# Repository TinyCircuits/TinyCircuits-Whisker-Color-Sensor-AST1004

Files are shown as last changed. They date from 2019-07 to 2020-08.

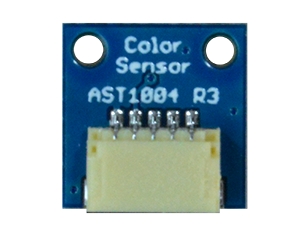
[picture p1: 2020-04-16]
images/AST1004-Learn-Photo-02.png

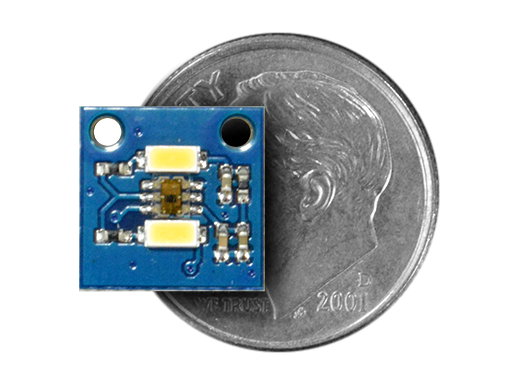
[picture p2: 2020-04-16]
images/AST1004-Product-Photo-03.png

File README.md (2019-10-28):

# TinyCircuits Wireling Color Sensor
# AST1004 Rev 2

The design files are located under design_files/ for the TinyCircuits AST1004 Rev 2 PCB. This is a Wireling board which measures the color and temperature of ambient or reflected light and also features a low power mode. Output resolution is 16-bit per each channel (Red, Green, and Blue). Includes bright white LEDs to aid sensing applications that can be toggled on or off.

Format is in Cadsoft Eagle format - Eagle version 6.2 was used for the original design.

For more infomation on this, check out the product page at TinyCircuits.com

# License:

Design by TinyCircuits.
All design files are released under the Creative Commons Attribution Share-Alike 3.0 License, see the following link for details: http://creativecommons.org/licenses/by-sa/3.0

All text above must be included in any redistribution or derived design

This project uses designs and concepts developed as part of the Arduino project and the LilyPad project.  The TinyCircuits design files themselves (schematics, PCB and libraries) are not directly derived from these works' design files and have been created new, however the concepts and basic architecture behind the TinyDuino and TinyLily products are derived and we thank the hard work of the organizations below for their contributions to open-source hardware:
  
Original Arduino Uno Design by Team Arduino

LilyPad Arduino Design by Leah Buechley and Sparkfun Electronics

Please support the open-source hardware community

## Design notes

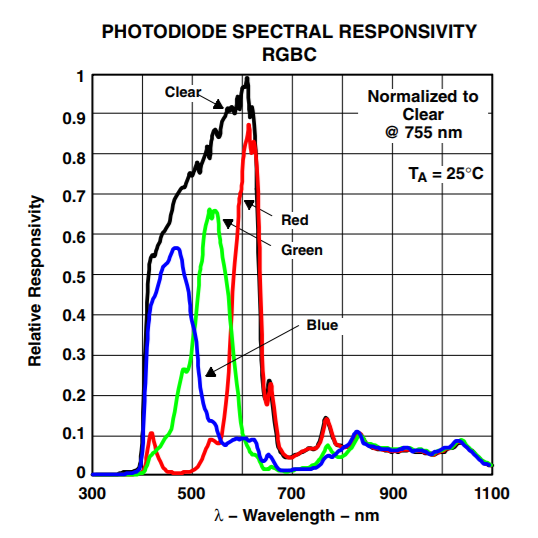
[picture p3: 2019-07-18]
images/Photodiode_Spectral_Responsivity.png

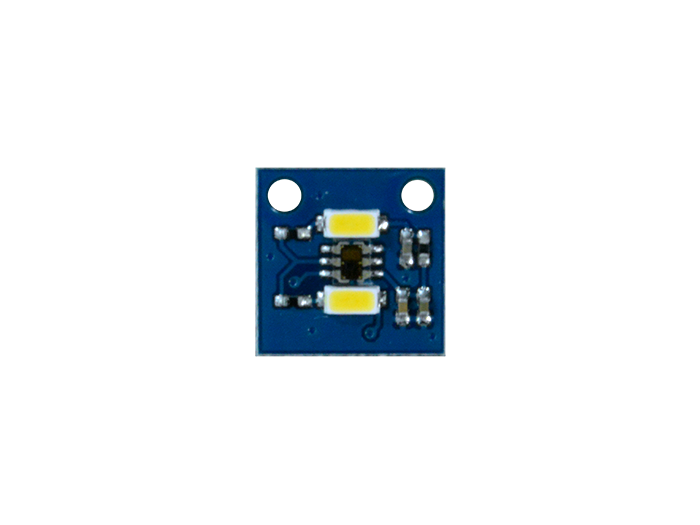
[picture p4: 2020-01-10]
images/AST1004-Product-Photo-01.png

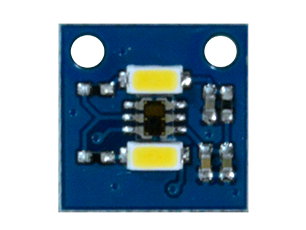
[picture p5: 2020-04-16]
images/AST1004-Learn-Photo-01.png

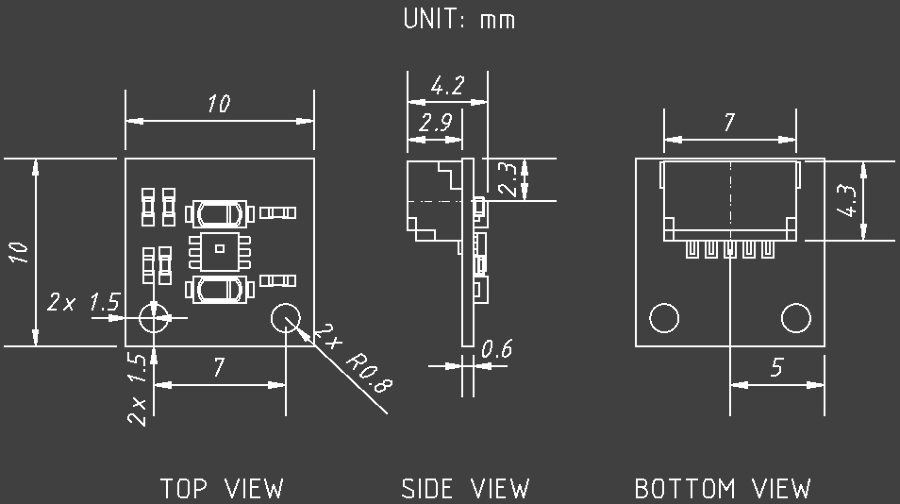
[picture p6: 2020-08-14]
cad/Wireling_COLORSENSOR_AST1004_REV3-DETAILED_DRAWING_COMPACT-PNG.png

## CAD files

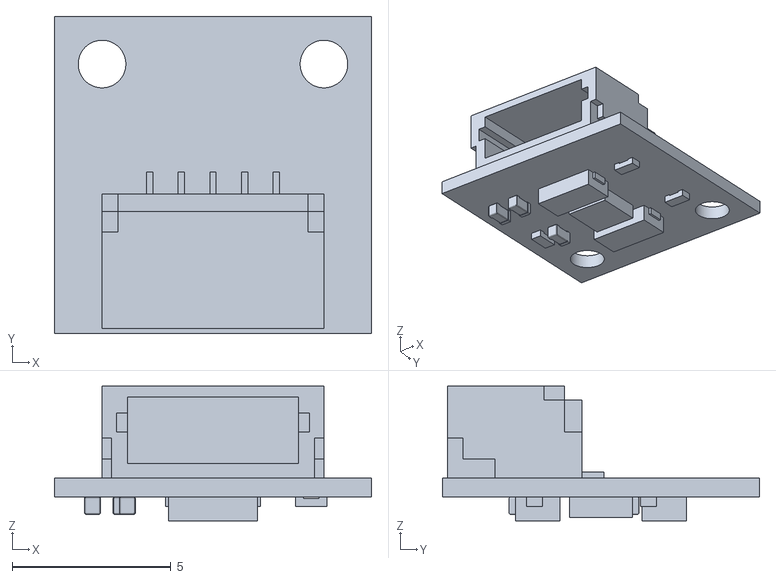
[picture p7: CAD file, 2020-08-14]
cad/Wireling_COLORSENSOR_AST1004_REV3-STL.stl
10.0 x 10.0 x 4.24

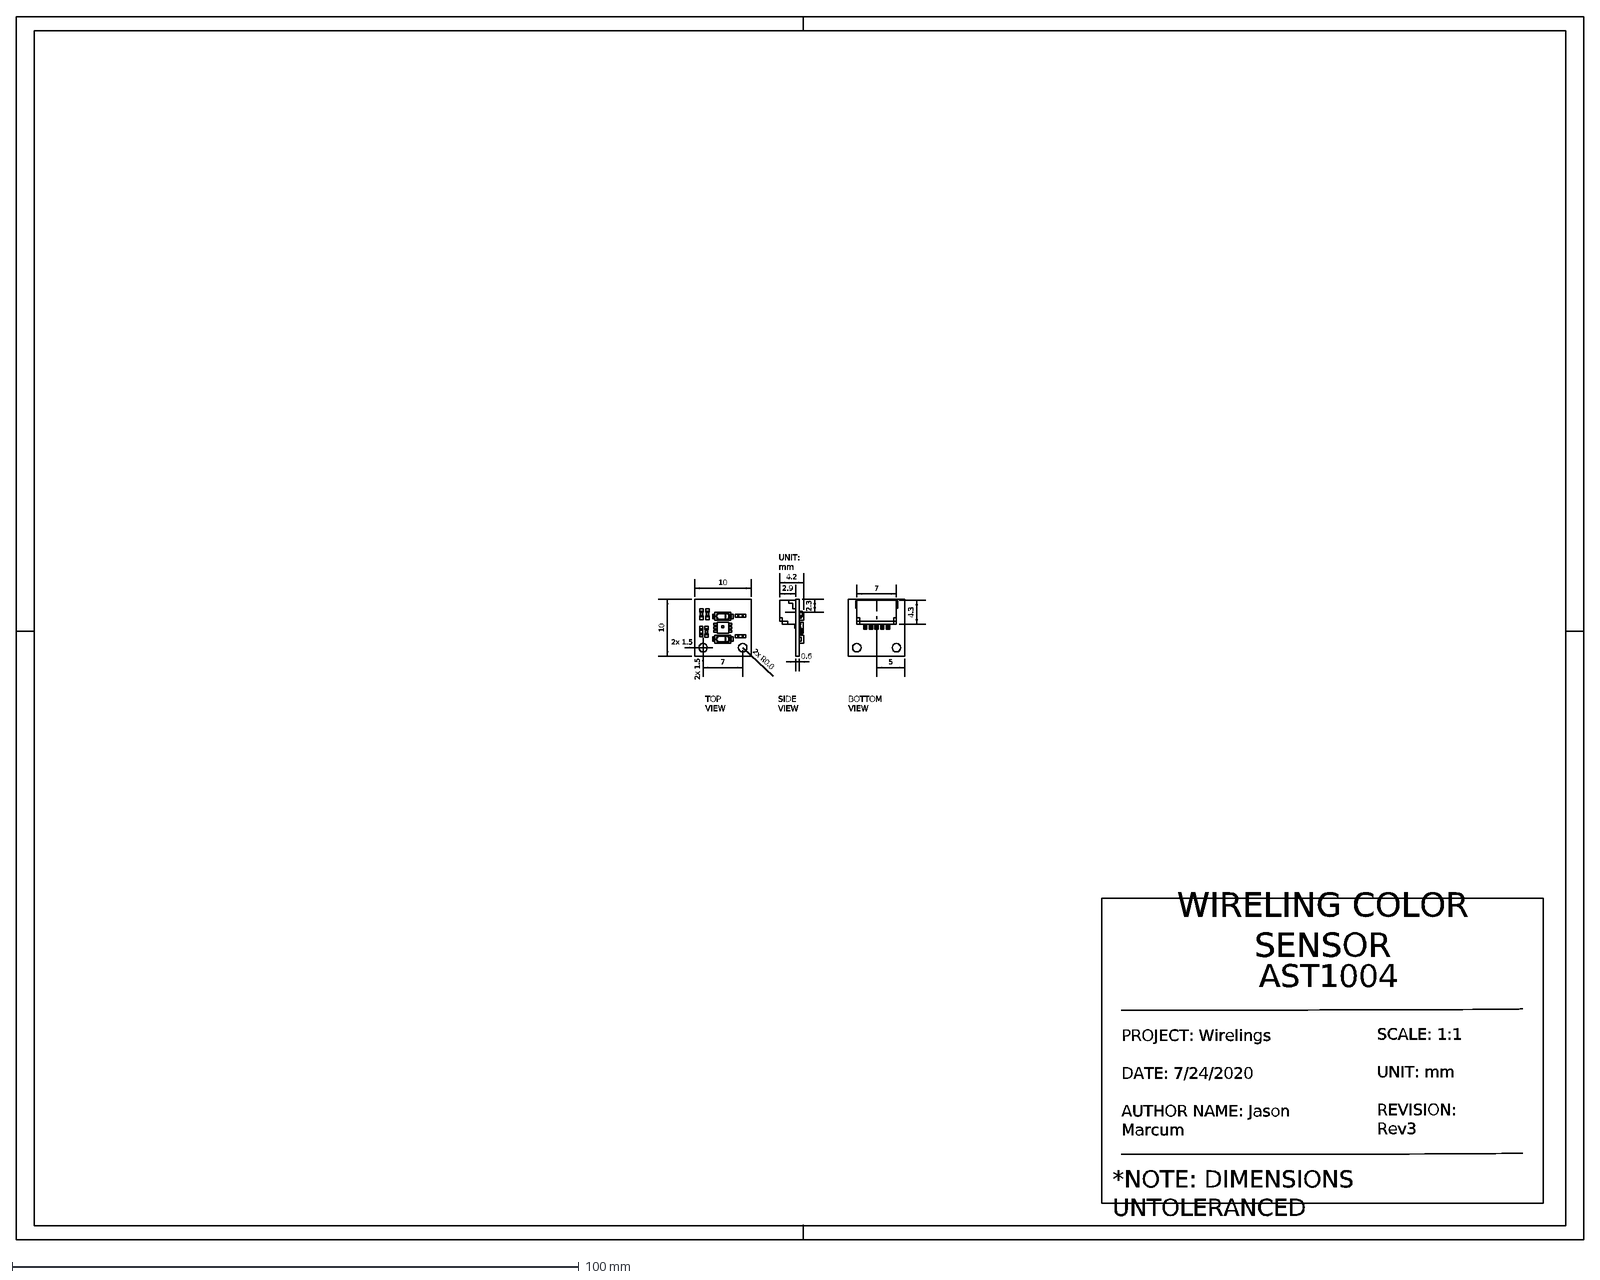
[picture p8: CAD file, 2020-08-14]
cad/Wireling_COLORSENSOR_AST1004_REV3-DETAILED_DRAWING-DXF.dxf
*NOTE: DIMENSIONS UNTOLERANCED
2x 1.5
7
10
2x R0.8
2.9
4.2
2.3
0.6
4.3
5
TOP VIEW
BOTTOM VIEW
SIDE VIEW
WIRELING COLOR SENSOR
AST1004
SCALE: 1:1 UNIT: mm REVISION: Rev3
UNIT: mm
PROJECT: Wirelings DATE: 7/24/2020 AUTHOR NAME: Jason Marcum

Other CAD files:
cad/Wireling_COLORSENSOR_AST1004_REV3-IGES.iges

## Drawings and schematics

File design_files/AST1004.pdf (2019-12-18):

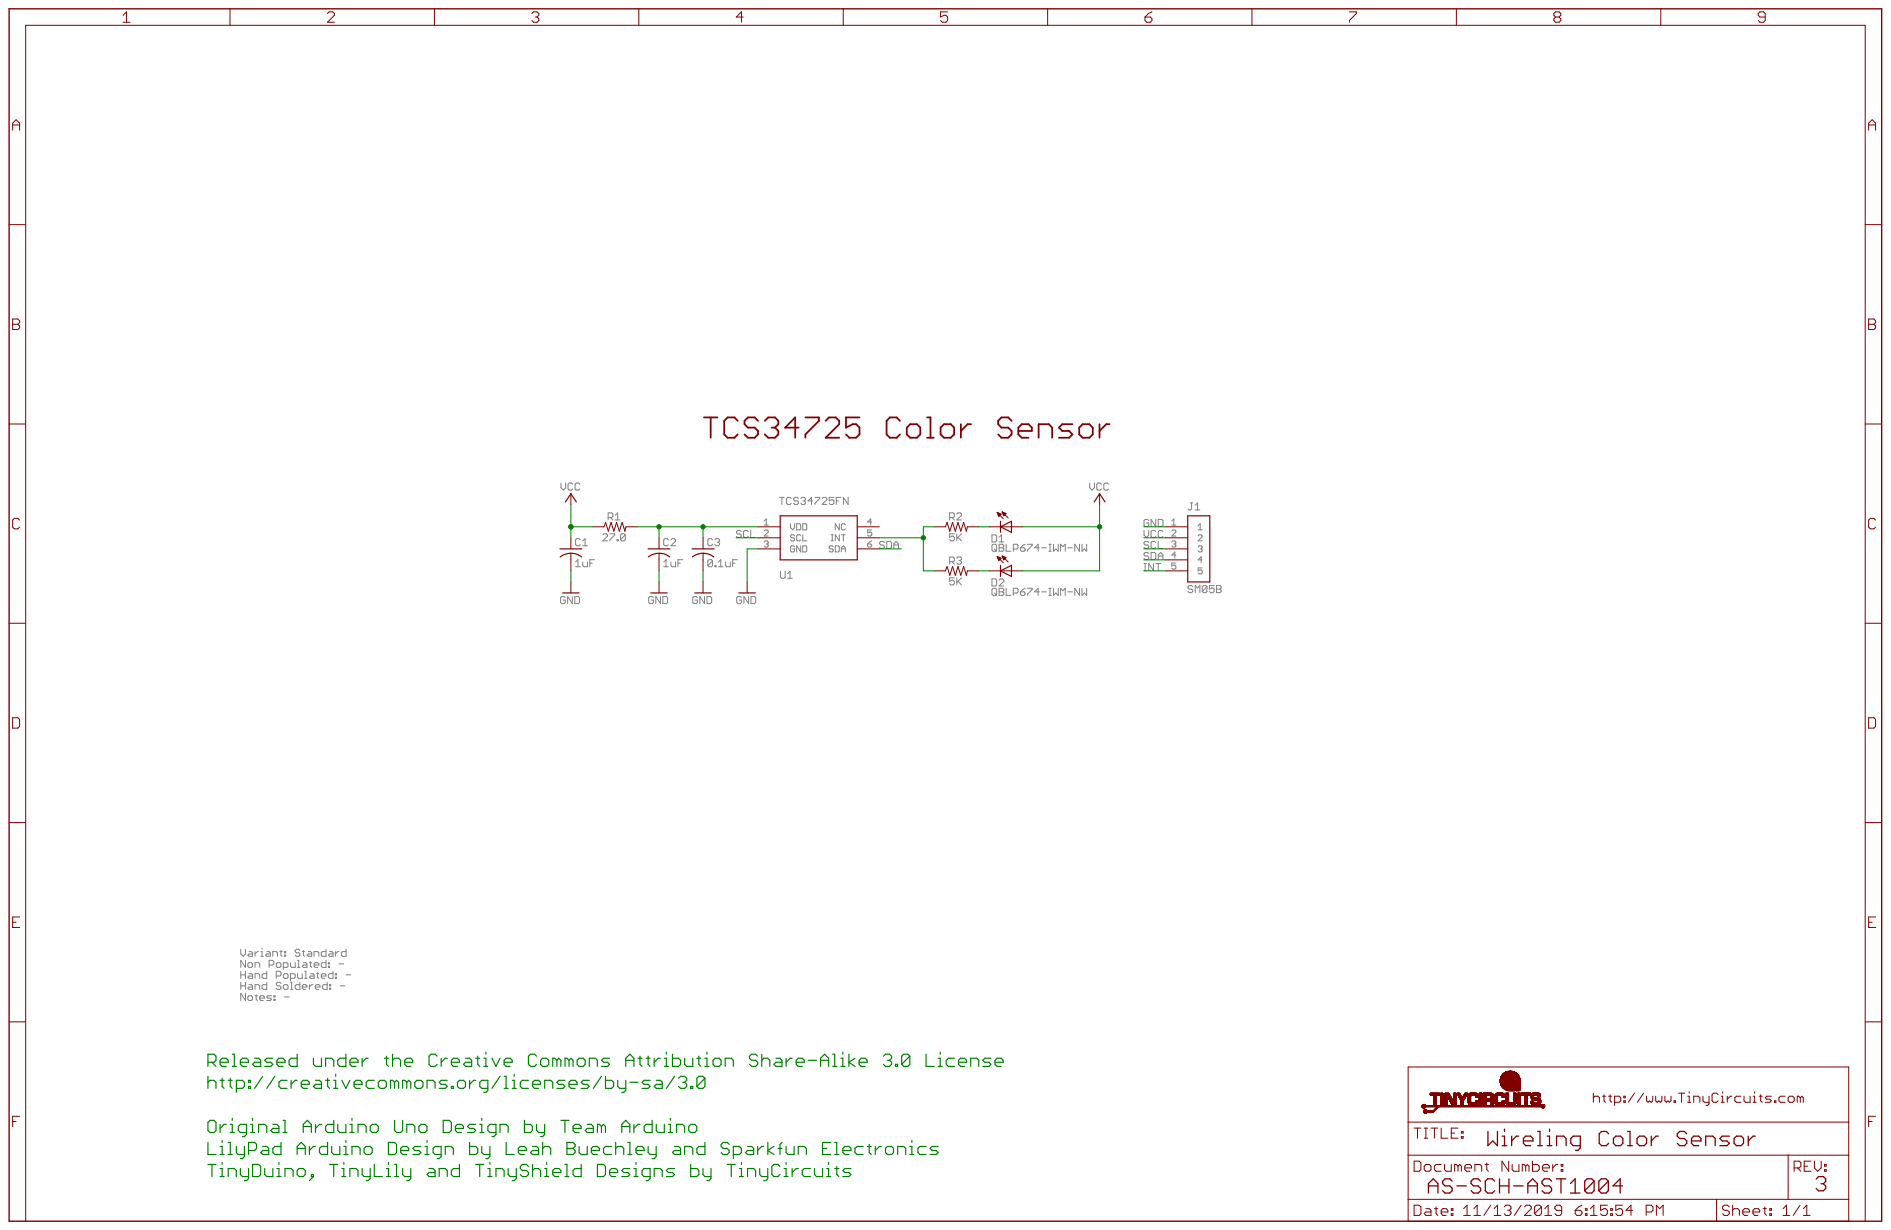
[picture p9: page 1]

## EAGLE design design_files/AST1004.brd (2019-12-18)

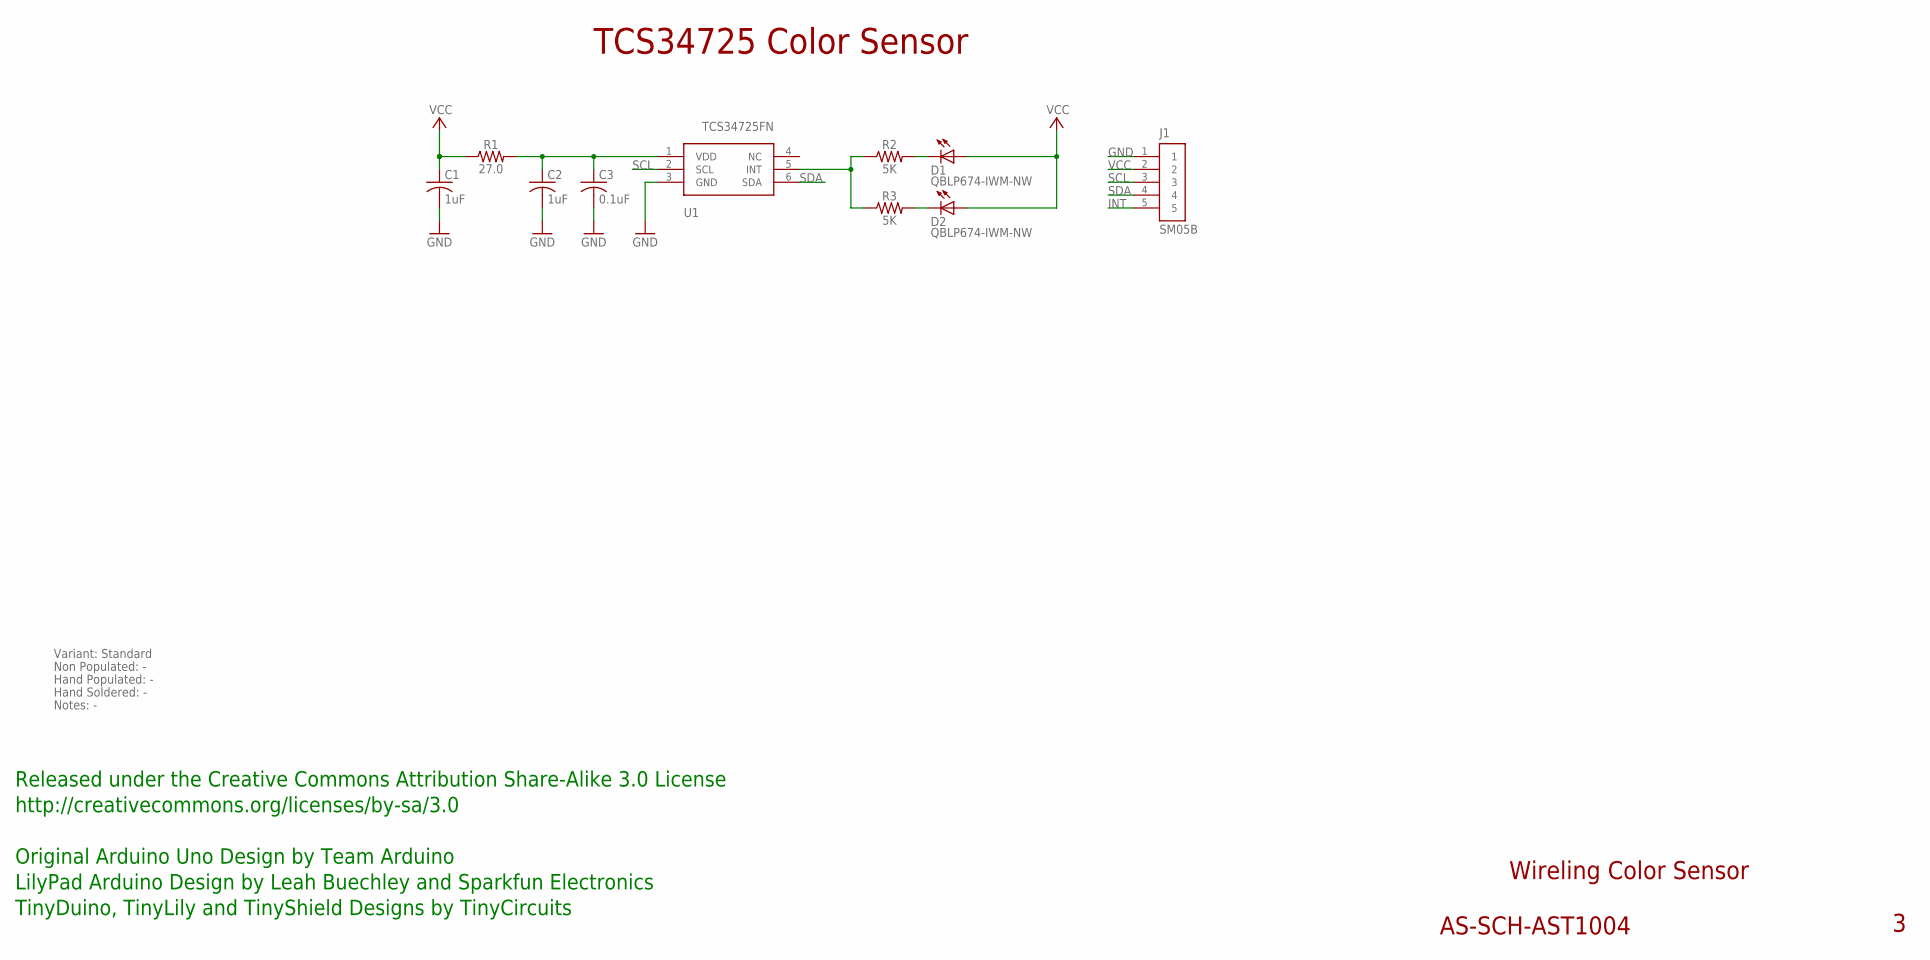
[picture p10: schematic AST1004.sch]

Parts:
C1, C2: 1uF; C0402; PARTNO AS-ITM-00105
C3: 0.1uF; C0402
D1, D2: QBLP674-IWM-NW; LED_TOP_2.8X1.4; PARTNO AS-ITM-00554
J1: SM05B; JST_SH_5X1_EDGE
R1: 27.0; 0402
R2, R3: 5K; 0402
U1: TCS34725FN; TSL2572; PARTNO AS-ITM-00140

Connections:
GND: C1.2, C2.2, C3.2, J1.1, U1.3 (GND)
INT: J1.5
unnamed: R2.1, R3.1, U1.5 (INT)
unnamed: C2.1, C3.1, R1.2, U1.1 (VDD)
unnamed: D2.C, R3.2
unnamed: D1.C, R2.2
SCL: J1.3, U1.2 (SCL)
SDA: J1.4, U1.6 (SDA)
VCC: C1.1, D1.A, D2.A, J1.2, R1.1

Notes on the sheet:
Wireling Color Sensor
AS-SCH-AST1004
TCS34725 Color Sensor
Released under the Creative Commons Attribution Share-Alike 3.0 License
http://creativecommons.org/licenses/by-sa/3.0
Original Arduino Uno Design by Team Arduino
TinyDuino, TinyLily and TinyShield Designs by TinyCircuits
LilyPad Arduino Design by Leah Buechley and Sparkfun Electronics
Variant: Standard
Non Populated: -
Hand Populated: -
Hand Soldered: -
Notes: -

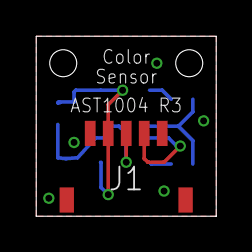
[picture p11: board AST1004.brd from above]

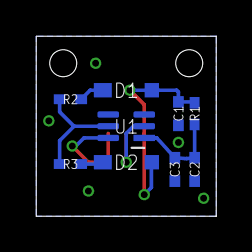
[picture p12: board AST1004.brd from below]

Board: 2 copper layers, 10.0 x 10.0 mm, 11 parts (9 on the bottom side), 8 nets.

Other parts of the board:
U$1: DOCFIELD-TINYCIRCUITS-PCB

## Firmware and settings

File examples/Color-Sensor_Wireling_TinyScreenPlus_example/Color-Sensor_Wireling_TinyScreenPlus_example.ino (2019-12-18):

/*************************************************************************
 * Color Sensor TCS34725 Wireling Tutorial:
 * This program will print the TCS34725 RGB, lux, and clearness values to 
 * the Serial Monitor and a TinyScreen+
 * 
 * Note: I²C Address for Wireling board is different than the Adafruit 
 * component, this address change is reflected in the library that
 * should be included with this sketch 
 * 
 * Hardware by: TinyCircuits
 * Code by: Laveréna Wienclaw for TinyCircuits
 *
 * Initiated: 11/29/2017 
 * Updated: 12/18/2019
 ************************************************************************/

#include <Wire.h>         // For I2C communication with sensor
#include <TinyScreen.h>   // For interfacing with the TinyScreen+
#include "Adafruit_TCS34725.h"  // The library used for the Color Sensor
#include <Wireling.h>     // For interfacing with Wirelings

/* Initialise with default values (int time = 2.4ms, gain = 1x) */
// Adafruit_TCS34725 tcs = Adafruit_TCS34725();

// Make compatible with all TinyCircuits processors
#if defined(ARDUINO_ARCH_AVR)
  #define SerialMonitorInterface Serial
#elif defined(ARDUINO_ARCH_SAMD)
  #define SerialMonitorInterface SerialUSB
#endif

/* Initialise with specific int time and gain values */
Adafruit_TCS34725 tcs = Adafruit_TCS34725(TCS34725_INTEGRATIONTIME_700MS, TCS34725_GAIN_1X);

// TinyScreen+ variables
TinyScreen display = TinyScreen(TinyScreenPlus);
int background = TS_8b_Black;

// Variables to hold the values the sensor reads
uint16_t r, g, b, c, colorTemp, lux;

void setup(void) {
  SerialMonitorInterface.begin(9600);
  Wire.begin();
  Wireling.begin();

  // Setup and style for TinyScreen+
  display.begin();
  display.setFlip(true);
  display.setBrightness(15);
  display.setFont(thinPixel7_10ptFontInfo);
  display.fontColor(TS_8b_White, background);

  //The port is the number on the Adapter board where the sensor is attached
  Wireling.selectPort(0);

  if (tcs.begin()) {
    SerialMonitorInterface.println("Found sensor");
  } else {
    SerialMonitorInterface.println("No TCS34725 found ... check your connections");
    while (1);
  }

  // Turn Wireling LEDs on 
  LEDon();
}

void loop(void) {
  tcs.getRawData(&r, &g, &b, &c);
  colorTemp = tcs.calculateColorTemperature(r, g, b);
  lux = tcs.calculateLux(r, g, b);

  SerialMonitorInterface.print("Color Temp: "); SerialMonitorInterface.print(colorTemp); SerialMonitorInterface.print(" K, ");
  SerialMonitorInterface.print("Lux: "); SerialMonitorInterface.print(lux, DEC); SerialMonitorInterface.print(", ");
  SerialMonitorInterface.print("R: "); SerialMonitorInterface.print(r, DEC); SerialMonitorInterface.print(", ");
  SerialMonitorInterface.print("G: "); SerialMonitorInterface.print(g, DEC); SerialMonitorInterface.print(", ");
  SerialMonitorInterface.print("B: "); SerialMonitorInterface.print(b); SerialMonitorInterface.print(", ");
  SerialMonitorInterface.print("Clr: "); SerialMonitorInterface.print(c, DEC);
  SerialMonitorInterface.println(" ");

  printScreen();

  delay(500);
}

// Turn Wireling LEDs on
void LEDon() {
  tcs.setInterrupt(true);
}

// Turn Wireling LEDs off
void LEDoff() {
  tcs.setInterrupt(false);
}

// Prints the color sensor values to the TinyScreen
void printScreen(void){
  // This will make the screen look a little unsteady but is needed in order
  // to clear old values 
  display.clearScreen();
  
  display.fontColor(TS_8b_DarkRed, background);
  display.setCursor(0, 0);
  display.print("ColorTemp = ");
  display.print(colorTemp);

  display.fontColor(TS_8b_Yellow, background);
  display.setCursor(0, 11);
  display.print("Lux = ");
  display.print(lux);

  display.fontColor(TS_8b_Red, background);
  display.setCursor(0, 22);
  display.print("R = ");
  display.print(r);

  display.fontColor(TS_8b_Green, background);
  display.setCursor(0, 33);
  display.print("G = ");
  display.print(g);

  display.fontColor(TS_8b_Blue, background);
  display.setCursor(0, 44);
  display.print("B = ");
  display.print(b);

  display.fontColor(TS_8b_White, background);
  display.setCursor(0, 55);
  display.print("Clr = ");
  display.print(c);
}

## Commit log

2019-09-24 fix program, add LED toggle
    [Color_Whisker_example.ino]
2019-11-21 LED Datasheet
2019-12-17 updated documentation
    [AST1004.brd, AST1004.sch]
2020-08-14 Add CAD data
    [Wireling_COLORSENSOR_AST1004_REV3-DETAILED_DRAWING-DXF.dxf, Wireling_COLORSENSOR_AST1004_REV3-IGES.iges, Wireling_COLORSENSOR_AST1004_REV3-STL.stl]
